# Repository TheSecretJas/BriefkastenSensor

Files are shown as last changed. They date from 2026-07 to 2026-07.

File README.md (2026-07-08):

# Briefkastensensor

Ein batteriebetriebener Sensor meldet Posteinwürfe per LoRa-Funk an ein
Gateway im Haus, das daraufhin eine E-Mail versendet und den Systemzustand
in einem lokalen Web-Portal bereitstellt. Das Projekt umfasst die komplette
Firmware (C++ / PlatformIO), die CAD-Modelle des Sensorhalters und den
fertigen G-Code für den 3D-Druck.

---

## Funktionsweise

Der Sender sitzt im Briefkasten und misst ein Mal pro Stunde per
Time-of-Flight-Sensor die Distanz zur Rückwand. Fällt die Distanz unter
65 mm, liegt ein Brief im Kasten: der Sender schickt eine
AES-verschlüsselte Meldung an das Gateway, das eine E-Mail an die
hinterlegten Empfänger versendet. Steigt die Distanz wieder über 75 mm
(Kasten geleert), setzt sich der Zustand automatisch zurück (Hysterese,
verhindert Mehrfachmeldungen). Analog überwacht der Sender seine
Akkuspannung (Warnung unter 3.45 V, Rücksetzen über 3.60 V).

Zusätzlich sendet der Sender bei jedem Aufwachen ein SYNC-Paket mit
Flags, Akkuspannung und Distanz. Das Gateway zeigt diese Werte zusammen
mit dem Raumklima in einem Web-Portal unter http://briefkastensensor.local/
an. Über das Portal lassen sich WLAN-, SMTP- und Empfänger-Einstellungen
ändern sowie die Sender-Flags ferngesteuert zurücksetzen: Nach jedem
SYNC lauscht der Sender zwei Sekunden auf Kommandos, das Gateway stellt
vorgemerkte Befehle in genau diesem Fenster zu (Class-A-Prinzip).

## Hardware

| Komponente | Funktion |
|---|---|
| Heltec Wireless Stick Lite V3 (ESP32-S3, SX1262, 868 MHz) | Sender im Briefkasten |
| Heltec WiFi LoRa 32 V3 (ESP32-S3, SX1262, OLED, 868 MHz) | Gateway im Haus |
| M5Stack Mini ToF Unit, 90 Grad (VL53L0X) | Distanzmessung zur Briefkasten-Rückwand |
| Waveshare BME280 | Raumklima am Gateway (Temperatur, Luftfeuchte) |
| Heltec 800 mAh LiPo 802540, 3.7 V | Stromversorgung des Senders |

### Pinbelegung

Beide Boards nutzen den gleichen SX1262-Anschluss: SPI an GPIO 8 (CS),
9 (SCK), 10 (MOSI), 11 (MISO), dazu DIO1 an 14, RST an 12, BUSY an 13.
Die Peripheriespannung (Vext, aktiv LOW) liegt auf GPIO 36.

Sender: VL53L0X per I2C an GPIO 41 (SDA) / 42 (SCL). Akkumessung über
GPIO 1 (ADC) mit Spannungsteiler-Freigabe an GPIO 37 und Teilerfaktor 4.9.

Gateway: OLED per I2C an GPIO 17 (SDA) / 18 (SCL), Reset an 21. BME280
(Adresse 0x77) am zweiten I2C-Bus an GPIO 41 / 42.

### Funkparameter

868 MHz, Bandbreite 125 kHz, Spreading Factor 9, Coding Rate 4/8,
Syncword 0x12 (privat), Sendeleistung -5 dBm, CRC aktiv. Alle Pakete sind
AES-128-CBC-verschlüsselt (Paketformat: 16 Byte Zufalls-IV plus
Ciphertext mit PKCS7-Padding).

## Mechanik: Sensorhalter (3D-Druck)

Der Halter ist zweiteilig aufgebaut:

1. **Aufnahme** (Briefkastensensorikaufnahme): wird fest in den
   Briefkasten eingeklebt und bleibt dauerhaft montiert.
2. **Deckel** (Briefkastendeckel): herausnehmbarer Einsatz, der die
   komplette Elektronik trägt: ToF-Sensor, Wireless Stick Lite V3 und
   den Akku. Zum Laden oder Flashen wird nur der Deckel entnommen, die
   verklebte Aufnahme bleibt im Kasten.

Der ToF-Sensor sitzt dank der 90-Grad-Bauform der M5Stack-Einheit flach
im Deckel und misst parallel zum Briefkastenboden auf die Rückwand.

Dateien im Ordner `CAD_Model/`:

| Datei | Inhalt |
|---|---|
| Briefkastensensorikaufnahme.CATPart | Aufnahme, CATIA-Quellmodell |
| Briefkastendeckel.CATPart | Deckel, CATIA-Quellmodell |
| Briefkastensensor.stl / Briefkastendeckel.stl | Exportierte Druckdaten |
| Zusammenbau.CATProduct / Product1.CATProduct | CATIA-Baugruppen beider Teile |

Im Ordner `3D_Print_GCode/` liegt fertig gesliceter G-Code für beide
Teile (Profil AI3MSPRO). Für andere Drucker die STL-Dateien mit dem
eigenen Slicer neu aufbereiten.

## Ordnerstruktur

```
.
|-- firmware/               C++ Firmware (PlatformIO-Projekt)
|   |-- src/sender/     Firmware Sendemodul
|   |-- src/gateway/    Firmware Gateway (SMTP, Web-Portal)
|   |-- src/common/     Gemeinsame Module (AES, NVS)
|   |-- src/provision/  Einmalige Zugangsdaten-Provisionierung
|   |-- README.md       Technische Details der Firmware
|   `-- ANLEITUNG.md    Schritt-für-Schritt: Setup und Flashen
|-- hardware/
|   |-- CAD_Model/          CATIA-Modelle und STL-Exporte des Halters
|   |-- 3D_Print_GCode/     Gesliceter G-Code für beide Druckteile
|-- docs/
```

## Software im Überblick

Die Firmware ist als PlatformIO-Projekt mit drei Umgebungen organisiert:

- `sender`: Deep-Sleep-Zyklus (1 h), Messung, Ereignis- und SYNC-Versand,
  2-Sekunden-Empfangsfenster für Gateway-Kommandos. Zustandsflags liegen
  im RTC-RAM; ein Power-Cycle setzt sie zurück.
- `gateway`: LoRa-Empfang per Interrupt, E-Mail-Versand über Gmail
  (Port 465, TLS mit Zertifikatsprüfung gegen GTS Root R1, NTP-Zeitsync),
  OLED-Anzeige, Web-Portal mit mDNS, Task-Watchdog.
- `provision`: liest die lokale `.env` beim Kompilieren ein und schreibt
  die Zugangsdaten einmalig in den NVS des jeweiligen Chips.

Verwendete Bibliotheken: RadioLib (SX1262), Adafruit SSD1306/GFX/BME280,
Pololu VL53L0X, mbedtls (AES, im ESP32-Framework enthalten).

## Sicherheit

- Alle Funkpakete sind AES-128-CBC-verschlüsselt; der Schlüssel wird
  ausschließlich per `.env`-Provisionierung gesetzt und ist bewusst
  nicht über das Web-Portal änderbar.
- Der SMTP-Versand prüft das Gmail-Zertifikat gegen das eingebettete
  Google-Root-Zertifikat (gültig bis 2036).
- Das Web-Portal ist per HTTP Basic Auth geschützt (PORTAL_PASS in der
  `.env`); gespeicherte Passwörter werden nie angezeigt.
- Bekannte Einschränkung: das Funkprotokoll enthält keinen
  Replay-Schutz. Ein mitgeschnittenes Paket könnte erneut gesendet
  werden und löst schlimmstenfalls eine überflüssige E-Mail oder ein
  Flag-Reset aus.

## Inbetriebnahme

Die vollständige Anleitung (PlatformIO-Setup, Flash-Erase, Provisionierung,
Flashen, Funktionstests, Fehlerbehebung) steht in `docs/ANLEITUNG.md`.
Kurzfassung:

```
cd firmware
cp .env.example .env          # Werte eintragen
pio run -e provision -t erase # pro Board: Flash löschen
pio run -e provision -t upload
pio run -e gateway -t upload  # bzw. -e sender
```

## Betrieb

- Der Sender meldet sich stündlich; "Letzter Kontakt" im Portal sollte
  60 Minuten nicht deutlich überschreiten.
- Akku laden: Deckel aus der Aufnahme nehmen, Akku bzw. Board per USB
  laden, Deckel wieder einsetzen und einmal RST drücken.
- Ein Flag-Reset über das Portal wird beim nächsten stündlichen
  Kontakt zugestellt.

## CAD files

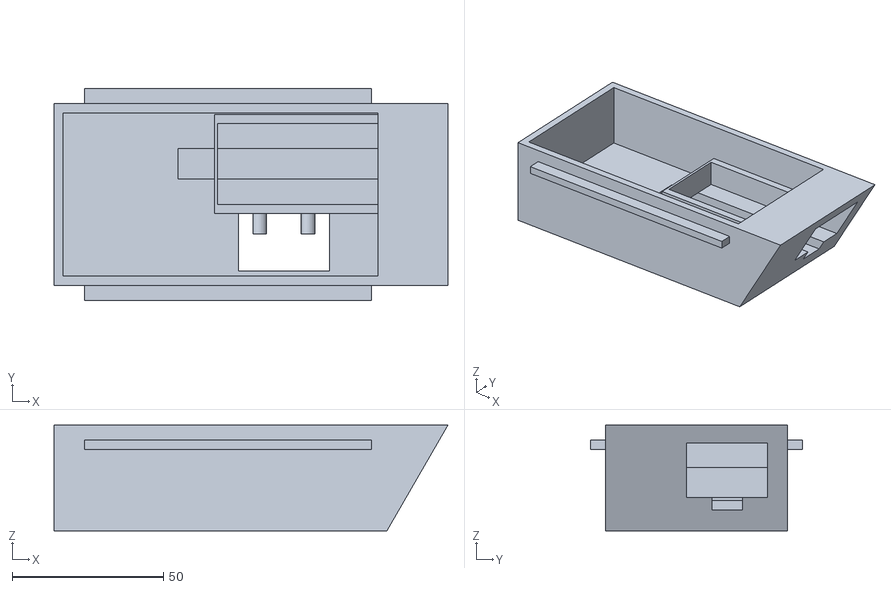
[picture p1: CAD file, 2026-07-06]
hardware/CAD_Model/Briefkastensensor.stl
130.2 x 70.0 x 35.0

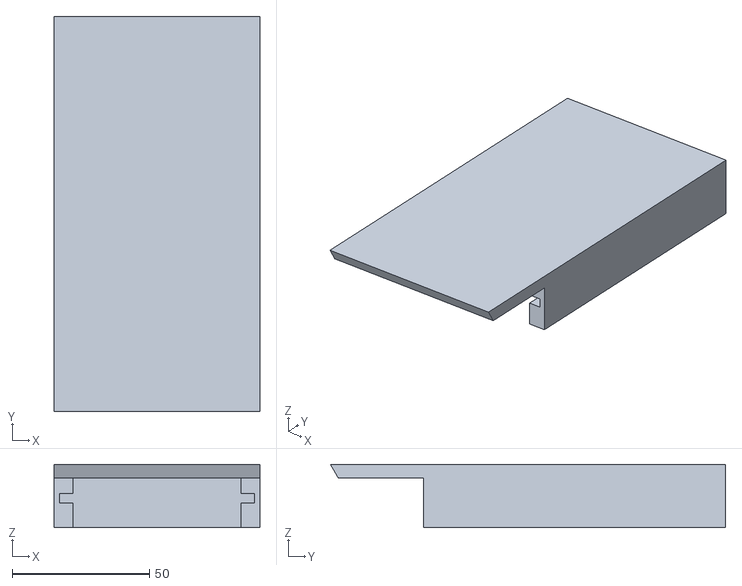
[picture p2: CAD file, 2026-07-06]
hardware/CAD_Model/Briefkastendeckel.stl
75.0 x 143.9 x 23.0

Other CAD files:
hardware/CAD_Model/Briefkastendeckel.CATPart
hardware/CAD_Model/Briefkastensensorikaufnahme.CATPart
hardware/CAD_Model/Product1.CATProduct
hardware/CAD_Model/Zusammenbau.CATProduct

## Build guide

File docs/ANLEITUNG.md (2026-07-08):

# Anleitung: PlatformIO-Setup und Inbetriebnahme

Projekt: Briefkastensensor / Autor: Jonas Thern
Hinweis: Diese Anleitung wurde mit Unterstützung von künstlicher Intelligenz (Claude, Anthropic) erstellt.

Diese Anleitung führt durch die Einrichtung von PlatformIO und die vollständige Inbetriebnahme beider Boards (Sender im Briefkasten und Gateway im Haus).

---

## 1. Voraussetzungen

Benötigt werden:

- Visual Studio Code (https://code.visualstudio.com)
- Die Erweiterung "PlatformIO IDE" (in VS Code: Extensions, nach "PlatformIO" suchen, installieren, VS Code danach neu starten). PlatformIO installiert Compiler, Toolchain und esptool beim ersten Build automatisch.
- Ein USB-C-Datenkabel (kein reines Ladekabel).
- Windows: falls das Board nach dem Anstecken nicht als COM-Port erscheint, den CP210x-Treiber von Silicon Labs installieren. Linux: der Benutzer muss in der Gruppe `dialout` sein (`sudo usermod -a -G dialout $USER`, danach neu anmelden).

Wichtig: Immer nur EIN Board gleichzeitig anschließen. PlatformIO wählt den Port automatisch; bei zwei angeschlossenen Boards kann sonst das falsche geflasht werden.

## 2. Projekt einrichten

1. Den Ordner `briefkasten-cpp` aus dem Zip an einen dauerhaften Ort entpacken.
2. In VS Code: "File > Open Folder" und den Ordner `briefkasten-cpp` öffnen. PlatformIO erkennt die `platformio.ini` und richtet das Projekt ein (erster Start dauert einige Minuten, da die ESP32-Plattform heruntergeladen wird).
3. Im Projektstamm die Datei `.env.example` als `.env` kopieren und alle Werte eintragen:
   - `AES_MAIN`: exakt 16 Zeichen, der gemeinsame Schlüssel für beide Boards
   - `WIFI_SSID` / `WIFI_PASS`: Zugangsdaten des Heimnetzes
   - `SMTP_USER` / `SMTP_PASS`: Gmail-Adresse und App-Passwort
   - `RECIPIENTS`: Empfänger, kommagetrennt
   - `PORTAL_PASS`: Passwort für das Web-Portal (dringend empfohlen, Benutzer ist `admin`)

   Die `.env` bleibt lokal auf dem Rechner und wird nie auf die Chips kopiert; die Werte wandern nur einmalig per Provisionierungs-Firmware in den NVS.

4. Ein Terminal in VS Code öffnen ("Terminal > New Terminal"). Falls der Befehl `pio` dort nicht gefunden wird, stattdessen das PlatformIO-eigene Terminal nutzen (PlatformIO-Symbol in der Seitenleiste > "PIO Terminal") oder die im Folgenden genannten Aufgaben über die PlatformIO-Oberfläche anklicken (Project Tasks > Umgebung > General/Platform).

## 3. Gateway einrichten (Heltec WiFi LoRa 32 V3)

Das Gateway zuerst einrichten, damit es bereitsteht, sobald der Sender das erste Mal sendet.

1. Gateway per USB anschließen (nur dieses Board).

2. Flash vollständig löschen. Das entfernt Reste einer eventuell zuvor installierten Firmware und alle alten NVS-Daten, sodass der Chip garantiert sauber startet:
   ```
   pio run -e provision -t erase
   ```
   Falls der Vorgang mit einem Verbindungsfehler abbricht: die PRG/BOOT-Taste auf dem Board gedrückt halten, kurz RST drücken, PRG loslassen und den Befehl wiederholen (das Board ist dann im Download-Modus).

3. Provisionierung flashen. Dabei liest das Build-Skript die `.env` und brennt eine Einmal-Firmware, die die Werte in den NVS schreibt:
   ```
   pio run -e provision -t upload
   pio device monitor
   ```
   Im Monitor muss erscheinen: "Gespeichert: aes_main", "Gespeichert: wifi_ssid" usw. und abschließend "Zugangsdaten erfolgreich im NVS gespeichert". Den Monitor mit Strg+C beenden. Erscheint stattdessen "Warnung: ... fehlt in der .env Datei", die `.env` prüfen und Schritt 3 wiederholen.

4. Gateway-Firmware flashen (die NVS-Daten bleiben dabei erhalten, es wird nur die Anwendung ersetzt):
   ```
   pio run -e gateway -t upload
   pio device monitor
   ```
   Erwarteter Ablauf im Monitor: WLAN verbindet, "Systemzeit gesetzt" (NTP, wichtig für den TLS-E-Mail-Versand), "Portal erreichbar unter http://briefkastensensor.local/", "Gateway betriebsbereit". Das OLED zeigt das Raumklima.

5. Portal testen: Im Browser eines Geräts im selben WLAN http://briefkastensensor.local/ öffnen und mit Benutzer `admin` und dem `PORTAL_PASS` anmelden. Falls die .local-Adresse nicht auflöst (ältere Windows-Versionen ohne Bonjour, manche Android-Geräte), die IP-Adresse aus der seriellen Ausgabe verwenden. Das Sendemodul zeigt zunächst überall "-", da noch kein SYNC-Paket eingegangen ist.

## 4. Sender einrichten (Heltec Wireless Stick Lite V3)

1. Gateway vom USB trennen (es kann weiter über den Akku oder ein Netzteil laufen), Sender anschließen.

2. Flash löschen, dann dieselbe Provisionierung flashen (identische `.env`, damit der AES-Schlüssel auf beiden Chips gleich ist):
   ```
   pio run -e provision -t erase
   pio run -e provision -t upload
   pio device monitor
   ```
   Ausgabe wie beim Gateway prüfen. WLAN- und SMTP-Werte landen zwar auch auf dem Sender, werden dort aber nicht verwendet; das ist unkritisch.

3. Sender-Firmware flashen:
   ```
   pio run -e sender -t upload
   pio device monitor
   ```
   Der Sender durchläuft sofort einen kompletten Messzyklus: Spannung und Distanz erscheinen im Monitor, dann "Sende Sync: SYNC ...", das zweisekündige Empfangsfenster und "Wechsle in Deep Sleep". Im Portal müssen jetzt Spannung, Distanz und Flags sichtbar sein.

   Hinweis: Im Deep Sleep ist der Chip für Uploads nicht ansprechbar. Für erneutes Flashen die RST-Taste drücken (der Upload startet dann während der Bootphase) oder den Download-Modus wie oben erzwingen.

## 5. Funktionstest vor dem Einbau

1. Posteinwurf simulieren: Hand oder Karton vor den ToF-Sensor (unter 65 mm), RST am Sender drücken. Erwartung: "STATUS NEW MAIL" im Log, E-Mail "Posteinwurf" kommt an, OLED zeigt "NEW MAIL ARRIVED", Portal zeigt "POST EINGEWORFEN".
2. Flag-Reset testen: Im Portal den Button "Sender-Flags zurücksetzen" klicken (Button zeigt "Reset wartet auf Sender..."), dann RST am Sender drücken. Der Sender empfängt das Kommando im Empfangsfenster, im Portal springt der Zustand auf "leer" zurück.
3. Danach den Sender im Briefkasten montieren und einmal RST drücken, damit Distanz-Nulllage und Portalanzeige zur realen Einbausituation passen.

## 6. Alltagsbetrieb und Stolpersteine

- Der Sender meldet sich stündlich per SYNC; "Letzter Kontakt" im Portal sollte nie deutlich über 60 Minuten steigen. Tut er es doch, ist Akku oder Funkstrecke zu prüfen.
- Ein Klick auf den Reset-Button wirkt erst beim nächsten stündlichen Kontakt (maximal 1 h Verzögerung); das ist konstruktionsbedingt, da der Sender dazwischen tief schläft.
- Konfigurationsänderungen im Portal (WLAN, SMTP, Empfänger) lösen einen Neustart des Gateways aus. Der AES-Schlüssel ist bewusst nur über eine erneute Provisionierung änderbar und muss dann auf BEIDEN Chips erneuert werden.
- Ein Power-Cycle des Senders (Akku ab und wieder an) setzt beide Flags auf null.
- Schlägt der E-Mail-Versand mit TLS-Fehlern fehl, zuerst prüfen, ob im Bootlog "Systemzeit gesetzt" erscheint (NTP braucht Internetzugang). Bleibt es bei Fehlern, könnte Google die Zertifikatskette gewechselt haben; dann `src/gateway/gts_root_r1.h` gemäß README aktualisieren.
- Upload schlägt fehl / Port nicht gefunden: anderes USB-Kabel testen, Download-Modus erzwingen (PRG halten, RST tippen, PRG loslassen), unter Windows Treiber prüfen. Wählt PlatformIO den falschen Port, diesen explizit angeben: `--upload-port COM5` (Windows) bzw. `--upload-port /dev/ttyUSB0` (Linux).
- "Could not open COM5, the port doesn't exist" bzw. "Zugriff verweigert": meist hält ein anderes Programm (z. B. ein noch offener serieller Monitor oder Thonny) den Port belegt. Programm schließen und Upload wiederholen.

## 7. Befehls-Kurzreferenz

```
pio run -e provision -t erase     Flash vollständig löschen (einmalig pro Board)
pio run -e provision -t upload    Zugangsdaten aus der .env in den NVS schreiben
pio run -e gateway -t upload      Gateway-Firmware flashen
pio run -e sender -t upload       Sender-Firmware flashen
pio device monitor -b 115200      Serielle Ausgabe ansehen (Strg+C beendet)
```

Alle Befehle sind in VS Code auch grafisch erreichbar: PlatformIO-Symbol in der Seitenleiste, dann "Project Tasks" und die jeweilige Umgebung (provision, gateway, sender).

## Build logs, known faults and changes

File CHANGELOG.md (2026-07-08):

# Changelog
All notable changes to this project will be documented in this file.

## [2.1.1] - 2026-07-08
### Changed
* **Changed:** Changed thresholds for mail detection

## [2.1.0] - 2026-07-08
### Added
* **TLS Security:** Embedded the Google Trust Services GTS Root R1 certificate and switched the SMTP client from `setInsecure()` to `setCACert()`, so the Gmail server certificate is now properly validated instead of trusted blindly.
* **Time Sync:** Added an NTP sync step on the gateway after WiFi connect, required for correct certificate validity checking.

## [2.0.0] - 2026-07-06
### Added
* **Full C++ Port:** Rewrote the entire project from MicroPython to C++ (PlatformIO, Arduino framework) to significantly reduce RAM usage. Three build environments (`sender`, `gateway`, `provision`) replace the previous single-script MicroPython layout.
* **LAN Web Portal:** New gateway web portal served via mDNS at `http://briefkastensensor.local/`, protected by HTTP Basic Auth (`PORTAL_PASS`). Displays live sender status (mail/battery flags, voltage, distance, last contact) and gateway room climate, and provides a JSON status API polled every 5 seconds.
* **Runtime Configuration:** Web portal now allows changing WLAN, SMTP, and recipient settings after initial provisioning, without reflashing. Password fields are write-only (blank = unchanged); the AES key remains provisioning-only for security.
* **Remote Flag Reset:** Added a Class-A-style downlink mechanism. The sender now transmits a `SYNC` packet (flags, battery voltage, distance) on every hourly wake cycle and opens a 2-second RX window; the gateway queues a `CMD RESET FLAGS` command from the portal and delivers it in that window, with the sender confirming via a second SYNC.
* **Provisioning via .env:** Replaced `setup_NVS.py` with a PlatformIO pre-build script (`scripts/load_env.py`) that injects `.env` values as compile-time defines for a one-time provisioning firmware, so credentials never live in a flashed file system.
### Changed
* **Crypto:** Ported the AES-CBC encryption/decryption to C++ using mbedtls, keeping the existing packet format (16-byte random IV + PKCS7-padded ciphertext) and NVS layout (`sys_sec` namespace, same blob keys) for full compatibility with already-provisioned chips.
* **State Persistence:** Replaced `rtc.memory()` string parsing with native `RTC_DATA_ATTR` variables; a power cycle now resets both flags automatically, making a separate reset script unnecessary.
* **Email Dispatch:** Rebuilt the SMTP client with watchdog-safe retry logic (up to five attempts) and deferred dispatch (~800 ms) so a long-running email send cannot block the sender's short LoRa receive window.
* **Reliability:** Added a task watchdog on the gateway main loop, fed both during normal operation and during SMTP transmission.
### Fixed
* **Portal Security:** Ensured stored secrets (WLAN/SMTP passwords) are never echoed back by the config API, and that the AES key cannot be modified via the web interface under any circumstances.

## [1.0.2] - 2026-06-08
### Added
* **Documentation:** Added clear logging and info regarding the automatic hysteresis logic (clarifying that a manual reset of the mail flag is not required).
### Changed
* **Power Management:** Optimized the deep sleep sequence to prevent leakage currents. I2C pins are now set to floating, the LoRa module is explicitly put into sleep mode, and the Vext power rail is disabled before entering deep sleep.
### Fixed
* **I2C Communication:** Enabled internal pull-up resistors (`machine.Pin.PULL_UP`) for SDA (Pin 41) and SCL (Pin 42) during initialization to prevent the VL53L0X sensor from freezing and locking the system state.

## [1.0.1] - 2026-06-06
### Added
* **CryptoEngine:** Implemented AES-CBC encryption with PKCS7 padding and a randomized IV. The AES key is now securely retrieved from Non-Volatile Storage (NVS).
* **State Persistence:** Added mailbox and battery state persistence utilizing the RTC memory to retain data across deep sleep cycles.
### Changed
* **TransmitterNode:** Refactored the main node logic to significantly improve overall power management, battery monitoring, and sensor checks.
* **Battery Monitoring:** ADC control is now specifically toggled during voltage reads to conserve power. Raw ADC values are properly converted to actual physical voltage.
* **Hysteresis Logic:** Introduced battery hysteresis thresholds (low/high) to reduce false state flips. 
* **Power Management:** Increased deep-sleep duration to 1 hour to reduce wakeups and extend battery life.
* **Code Quality:** Renamed and documented distance thresholds, applied structural cleanups, and enhanced logging to strengthen system reliability and message confidentiality.

## [1.0.0] - 2026-03-15
### Added
* **Initial Release:** Initial commit of the project.
* **Documentation:** Created project structure and added the initial README file.

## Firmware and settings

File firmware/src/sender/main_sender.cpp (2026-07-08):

// ============================================================
// Datei:   main_sender.cpp
// Projekt: Briefkastensensor (C++ Portierung von MicroPython)
// Autor:   Jonas Thern
// Hinweis: Kommentare und Formatierung wurden mit Unterstuetzung
//          von kuenstlicher Intelligenz (Claude, Anthropic) erstellt.
// ============================================================
// Sendemodul im Briefkasten (Heltec Wireless Stick Lite V3, ESP32-S3).
// Ablauf pro Zyklus: Aufwachen, Akkuspannung und Distanz messen,
// bei Ereignis verschluesselte LoRa-Nachricht senden, Zustaende im
// RTC-RAM sichern und fuer eine Stunde in den Deep Sleep wechseln.

#include <Arduino.h>
#include <Wire.h>
#include <SPI.h>
#include <RadioLib.h>
#include <VL53L0X.h>
#include "esp_sleep.h"

#include "../common/nvs_config.h"
#include "../common/aes_crypto.h"

// ------------------------------------------------------------
// Pinbelegung (identisch zur MicroPython-Version)
// ------------------------------------------------------------
static const int PIN_VEXT      = 36;  // Spannungsversorgung Peripherie, aktiv LOW
static const int PIN_ADC_CTRL  = 37;  // Spannungsteiler-Steuerung, aktiv LOW
static const int PIN_ADC_BATT  = 1;   // Akkuspannung ueber Spannungsteiler

static const int PIN_I2C_SDA   = 41;
static const int PIN_I2C_SCL   = 42;

static const int PIN_LORA_SCK  = 9;
static const int PIN_LORA_MOSI = 10;
static const int PIN_LORA_MISO = 11;
static const int PIN_LORA_CS   = 8;
static const int PIN_LORA_DIO1 = 14;
static const int PIN_LORA_RST  = 12;
static const int PIN_LORA_BUSY = 13;

// ------------------------------------------------------------
// Schwellwerte und Zeiten (identisch zur MicroPython-Version)
// ------------------------------------------------------------
static const uint16_t DIST_THRESH_FULL  = 58;   // mm, Brief erkannt
static const uint16_t DIST_THRESH_EMPTY = 60;   // mm, Kasten geleert
static const float    BATT_THRESH_LOW   = 3.45; // V, Warnung ausloesen
static const float    BATT_THRESH_HIGH  = 3.60; // V, Warnung zuruecksetzen
static const uint64_t SLEEP_US          = 3600ULL * 1000000ULL; // 1 Stunde
static const uint32_t RX_WINDOW_MS      = 2000; // Empfangsfenster nach SYNC

// Zustaende ueberleben den Deep Sleep im RTC-RAM.
// Ersetzt rtc.memory() aus MicroPython, ein Power-Cycle setzt beide
// Flags automatisch auf null (ersetzt resett_flags.py).
RTC_DATA_ATTR uint8_t mail_state = 0;
RTC_DATA_ATTR uint8_t batt_state = 0;

// LoRa-Funkmodul an eigenem SPI-Bus
SPIClass  spi_lora(HSPI);
SX1262    radio = new Module(PIN_LORA_CS, PIN_LORA_DIO1, PIN_LORA_RST,
                             PIN_LORA_BUSY, spi_lora);

VL53L0X   tof_sensor;
AesCrypto crypto;

// RX-Flag fuer das Empfangsfenster nach dem SYNC-Paket
volatile bool rx_flag = false;

void IRAM_ATTR onLoraReceive() {
    rx_flag = true;
}

// ------------------------------------------------------------
// Akkuspannung messen: Spannungsteiler aktivieren, wandeln,
// wieder deaktivieren um Ruhestrom zu vermeiden
// ------------------------------------------------------------
static float readBatteryVoltage() {
    digitalWrite(PIN_ADC_CTRL, LOW);
    delay(50);
    int raw = analogRead(PIN_ADC_BATT);
    digitalWrite(PIN_ADC_CTRL, HIGH);
    // 12 Bit Aufloesung, 11 dB Daempfung, Hardware-Teilerfaktor 4.9
    return (raw / 4095.0f) * 3.3f * 4.9f;
}

// ------------------------------------------------------------
// Verschluesselte Statusnachricht senden
// ------------------------------------------------------------
static void sendEncrypted(const char* text) {
    uint8_t packet[80];
    size_t len = crypto.encrypt(String(text), packet, sizeof(packet));
    if (len == 0) return;

    int state = radio.transmit(packet, len);
    if (state == RADIOLIB_ERR_NONE) {
        Serial.println("Uebertragung erfolgreich");
    } else {
        Serial.print("Fehler: LoRa Uebertragung, Code ");
        Serial.println(state);
    }
}

// ------------------------------------------------------------
// SYNC-Paket: macht dem Gateway die Flags, die Akkuspannung und
// die Distanz bekannt (loest dort keine E-Mail aus)
// ------------------------------------------------------------
static void sendSync(float voltage, uint16_t distance) {
    char msg[48];
    snprintf(msg, sizeof(msg), "SYNC %u,%u,%.2f,%u",
             (unsigned)mail_state, (unsigned)batt_state, voltage, (unsigned)distance);
    Serial.print("Sende Sync: ");
    Serial.println(msg);
    sendEncrypted(msg);
}

// ------------------------------------------------------------
// Empfangsfenster nach dem SYNC: das Gateway kann jetzt ein
// vorgemerktes Kommando zustellen (Class-A-artiger Downlink).
// Rueckgabe: true wenn ein Flag-Reset ausgefuehrt wurde.
// ------------------------------------------------------------
static bool listenForCommand() {
    rx_flag = false;
    radio.setDio1Action(onLoraReceive);
    if (radio.startReceive() != RADIOLIB_ERR_NONE) {
        return false;
    }

    uint32_t start = millis();
    while (millis() - start < RX_WINDOW_MS && !rx_flag) {
        delay(5);
    }

    bool did_reset = false;
    if (rx_flag) {
        uint8_t payload[80];
        size_t len = radio.getPacketLength();
        if (len > sizeof(payload)) len = sizeof(payload);
        if (radio.readData(payload, len) == RADIOLIB_ERR_NONE && len > 0) {
            String decoded = crypto.decrypt(payload, len);
            if (decoded == "CMD RESET FLAGS") {
                Serial.println("Kommando empfangen: Flags werden zurueckgesetzt");
                mail_state = 0;
                batt_state = 0;
                did_reset = true;
            } else if (decoded.length() > 0) {
                Serial.println("Unbekanntes Kommando verworfen");
            }
        }
    }

    radio.clearDio1Action();
    radio.standby();
    return did_reset;
}

// ------------------------------------------------------------
// Abschaltsequenz und Deep Sleep
// ------------------------------------------------------------
static void enterDeepSleep() {
    Serial.println("Zyklus abgeschlossen, bereite Deep Sleep vor");

    // I2C-Leitungen hochohmig schalten, damit der stromlose Sensor
    // nicht ueber die Pull-ups phantomgespeist wird
    Wire1.end();
    pinMode(PIN_I2C_SDA, INPUT);
    pinMode(PIN_I2C_SCL, INPUT);

    // Funkmodul explizit in den Schlafmodus versetzen
    radio.sleep();

    // Peripheriespannung abschalten
    digitalWrite(PIN_VEXT, HIGH);

    Serial.println("Wechsle in Deep Sleep");
    esp_sleep_enable_timer_wakeup(SLEEP_US);
    esp_deep_sleep_start();
}

void setup() {
    Serial.begin(115200);
    delay(100);

    // Peripheriespannung aktivieren
    Serial.println("Aktiviere Vext Spannungsversorgung");
    pinMode(PIN_VEXT, OUTPUT);
    digitalWrite(PIN_VEXT, LOW);
    delay(800);

    Serial.println("Initialisiere Subsysteme");

    // ADC vorbereiten
    pinMode(PIN_ADC_CTRL, OUTPUT);
    digitalWrite(PIN_ADC_CTRL, HIGH);
    analogReadResolution(12);
    analogSetPinAttenuation(PIN_ADC_BATT, ADC_11db);

    // AES-Schluessel aus dem NVS laden
    NvsConfig cfg;
    if (!cfg.begin()) {
        Serial.println("Fehler: Konfiguration fehlt, Abbruch in den Sleep");
        enterDeepSleep();
    }
    uint8_t key[AesCrypto::KEY_LEN];
    if (cfg.readBlob("aes_main", key, sizeof(key)) != AesCrypto::KEY_LEN) {
        Serial.println("Fehler: AES Schluessel ungueltig, Abbruch in den Sleep");
        enterDeepSleep();
    }
    crypto.setKey(key);

    // I2C-Bus mit internen Pull-ups und ToF-Sensor initialisieren
    Wire1.begin(PIN_I2C_SDA, PIN_I2C_SCL);
    tof_sensor.setBus(&Wire1);
    tof_sensor.setTimeout(1000);
    bool tof_ok = tof_sensor.init();
    if (!tof_ok) {
        Serial.println("Fehler: VL53L0X nicht erreichbar");
    }

    // LoRa-Funkmodul fuer das 868 MHz Band konfigurieren
    spi_lora.begin(PIN_LORA_SCK, PIN_LORA_MISO, PIN_LORA_MOSI, PIN_LORA_CS);
    int state = radio.begin(868.0, 125.0, 9, 8, 0x12, -5, 8, 1.7, false);
    if (state != RADIOLIB_ERR_NONE) {
        Serial.print("Fehler: LoRa Initialisierung, Code ");
        Serial.println(state);
        enterDeepSleep();
    }
    radio.setCurrentLimit(60.0);
    radio.setCRC(true);

    // 1. Akkuzustand mit Hysterese auswerten
    float voltage = readBatteryVoltage();
    Serial.print("Gemessene Spannung ");
    Serial.print(voltage, 2);
    Serial.println(" V");

    if (batt_state == 0 && voltage < BATT_THRESH_LOW) {
        Serial.println("Alarm: Spannung kritisch niedrig, starte Uebertragung");
        sendEncrypted("STATUS BATTERY LOW");
        batt_state = 1;
    } else if (batt_state == 1 && voltage > BATT_THRESH_HIGH) {
        Serial.println("Info: Spannung erholt, setze Zustand zurueck");
        batt_state = 0;
    }

    // 2. Briefkastenzustand mit Hysterese auswerten
    uint16_t distance = 0;
    if (tof_ok) {
        distance = tof_sensor.readRangeSingleMillimeters();
        if (tof_sensor.timeoutOccurred()) {
            Serial.println("Fehler: ToF Timeout, Messung wird uebersprungen");
            distance = 0;
        } else {
            Serial.print("Gemessene Distanz ");
            Serial.print(distance);
            Serial.println(" mm");

            if (mail_state == 0 && distance < DIST_THRESH_FULL) {
                Serial.println("Alarm: Distanzschwelle unterschritten, starte Uebertragung");
                sendEncrypted("STATUS NEW MAIL");
                mail_state = 1;
            } else if (mail_state == 1 && distance > DIST_THRESH_EMPTY) {
                Serial.println("Info: Distanz wiederhergestellt, setze Zustand zurueck");
                mail_state = 0;
            }
        }
    }

    // 3. SYNC-Paket mit aktuellem Zustand an das Gateway senden.
    // Es dient dem Portal (Flags, Akkuspannung, Distanz) und oeffnet
    // zugleich das Zeitfenster fuer ferngesteuerte Kommandos.
    sendSync(voltage, distance);

    // 4. Kurzes Empfangsfenster fuer ein vorgemerktes Reset-Kommando
    if (listenForCommand()) {
        // Reset bestaetigen, damit das Portal den neuen Zustand anzeigt
        sendSync(voltage, distance);
    }

    // 5. Abschalten und schlafen
    enterDeepSleep();
}

void loop() {
    // Wird nur erreicht, wenn der Deep Sleep nicht betreten wurde.
    // Sicherheitshalber erneut versuchen statt still zu haengen.
    Serial.println("Warnung: Deep Sleep nicht betreten, erneuter Versuch");
    delay(1000);
    enterDeepSleep();
}

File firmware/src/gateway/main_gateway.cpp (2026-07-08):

// ============================================================
// Datei:   main_gateway.cpp
// Projekt: Briefkastensensor (C++ Portierung von MicroPython)
// Autor:   Jonas Thern
// Hinweis: Kommentare und Formatierung wurden mit Unterstuetzung
//          von kuenstlicher Intelligenz (Claude, Anthropic) erstellt.
// ============================================================
// Gateway (Heltec WiFi LoRa 32 V3, ESP32-S3). Empfaengt verschluesselte
// LoRa-Statusmeldungen des Briefkastensensors, entschluesselt sie und
// versendet E-Mail-Benachrichtigungen. Das OLED zeigt Raumklima
// (BME280) und Systemstatus an. Ein Watchdog ueberwacht die Hauptschleife.
//
// Zusaetzlich stellt das Gateway ein LAN-Web-Portal unter
// http://briefkastensensor.local/ bereit. Es zeigt den Zustand des
// Sendemoduls (SYNC-Pakete: Flags, Akkuspannung, Distanz), erlaubt
// Konfigurationsaenderungen und kann ein Flag-Reset-Kommando an den
// Sender zustellen. SYNC-Pakete loesen keine E-Mail aus.

#include <Arduino.h>
#include <Wire.h>
#include <SPI.h>
#include <WiFi.h>
#include <RadioLib.h>
#include <Adafruit_GFX.h>
#include <Adafruit_SSD1306.h>
#include <Adafruit_BME280.h>
#include "esp_task_wdt.h"
#include <time.h>

#include "../common/nvs_config.h"
#include "../common/aes_crypto.h"
#include "smtp_client.h"
#include "web_portal.h"

// ------------------------------------------------------------
// Pinbelegung (identisch zur MicroPython-Version)
// ------------------------------------------------------------
static const int PIN_VEXT      = 36;  // aktiv LOW
static const int PIN_OLED_RST  = 21;
static const int PIN_OLED_SDA  = 17;
static const int PIN_OLED_SCL  = 18;

static const int PIN_EXT_SDA   = 41;  // BME280
static const int PIN_EXT_SCL   = 42;

static const int PIN_LORA_SCK  = 9;
static const int PIN_LORA_MOSI = 10;
static const int PIN_LORA_MISO = 11;
static const int PIN_LORA_CS   = 8;
static const int PIN_LORA_DIO1 = 14;
static const int PIN_LORA_RST  = 12;
static const int PIN_LORA_BUSY = 13;

static const uint32_t WDT_TIMEOUT_S = 15;
static const uint32_t ALERT_HOLD_S  = 60;   // Anzeigedauer des Postalarms
static const uint32_t BURST_WAIT_MS = 800;  // Wartezeit auf Folgepakete

// ------------------------------------------------------------
// Globale Objekte und Zustaende
// ------------------------------------------------------------
SPIClass         spi_lora(HSPI);
SX1262           radio = new Module(PIN_LORA_CS, PIN_LORA_DIO1, PIN_LORA_RST,
                                    PIN_LORA_BUSY, spi_lora);
Adafruit_SSD1306 display(128, 64, &Wire, PIN_OLED_RST);
Adafruit_BME280  bme;
AesCrypto        crypto;
NvsConfig        cfg;
WebPortal        portal;

SmtpClient*         mailer = nullptr;
std::vector<String> recipients;

String   sys_status   = "RX Ready";
uint32_t status_until = 0;
bool     alert_active = false;
uint32_t alert_time   = 0;
bool     bme_ok       = false;

// Aufgeschobener E-Mail-Versand: wird erst nach dem Abarbeiten
// eines Paket-Bursts ausgefuehrt, damit das Reset-Kommando das
// Empfangsfenster des Senders nicht verpasst
String pending_subject;
String pending_body;

// RX-Flag wird in der Interruptroutine gesetzt
volatile bool msg_flag = false;

// ------------------------------------------------------------
// Interruptroutine, ausgeloest durch DIO1 bei empfangenem Paket
// ------------------------------------------------------------
void IRAM_ATTR onLoraReceive() {
    msg_flag = true;
}

// ------------------------------------------------------------
// OLED-Anzeige: Raumklima und Statuszeile
// ------------------------------------------------------------
static void updateScreen() {
    display.clearDisplay();
    display.setTextSize(1);
    display.setTextColor(SSD1306_WHITE);

    display.setCursor(0, 0);
    if (alert_active) {
        display.print("NEW MAIL ARRIVED");
    } else {
        display.print("ROOM CLIMATE");
    }

    if (bme_ok) {
        float temp_c = bme.readTemperature();
        float hum_p  = bme.readHumidity();
        display.setCursor(0, 20);
        display.print("Temp ");
        display.print(temp_c, 1);
        display.print(" C");
        display.setCursor(0, 35);
        display.print("Hum  ");
        display.print(hum_p, 1);
        display.print(" %");
    } else {
        display.setCursor(0, 20);
        display.print("BME280 Fehler");
    }

    display.setCursor(0, 55);
    display.print(sys_status);
    display.display();
}

// ------------------------------------------------------------
// Logausgabe auf Konsole und OLED-Statuszeile
// ------------------------------------------------------------
static void logUi(const String& console_text, const String& oled_text = "",
                  uint32_t duration_s = 2) {
    Serial.println(console_text);
    sys_status = oled_text.length() ? oled_text : console_text.substring(0, 16);
    status_until = millis() / 1000 + duration_s;
    updateScreen();
}

// ------------------------------------------------------------
// WLAN-Verbindung mit Wiederholversuchen aufbauen
// ------------------------------------------------------------
static void initWlan() {
    String ssid = cfg.readString("wifi_ssid");
    String pwd  = cfg.readString("wifi_pass");
    if (ssid.length() == 0) {
        Serial.println("Fehler: WLAN Zugangsdaten fehlen");
        return;
    }

    for (int attempt = 1; attempt <= 3; attempt++) {
        Serial.print("WLAN Verbindungsversuch ");
        Serial.println(attempt);
        WiFi.disconnect(true);
        delay(500);
        WiFi.mode(WIFI_STA);
        // Modem-Sleep deaktivieren, damit das Portal fluessig reagiert
        WiFi.setSleep(false);
        WiFi.begin(ssid.c_str(), pwd.c_str());

        int timeout = 40;  // 40 x 500 ms = 20 Sekunden
        while (WiFi.status() != WL_CONNECTED && timeout > 0) {
            delay(500);
            timeout--;
        }
        if (WiFi.status() == WL_CONNECTED) {
            Serial.println("WLAN erfolgreich verbunden");
            return;
        }
        Serial.println("Verbindung fehlgeschlagen, neuer Versuch");
    }
    Serial.println("Fehler: Kritischer WLAN Ausfall");
}
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
